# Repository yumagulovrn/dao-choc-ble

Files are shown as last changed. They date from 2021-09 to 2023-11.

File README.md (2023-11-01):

# Dao Choc BLE Keyboard

Dao Choc BLE (https://i.imgur.com/4VNZkyh.jpg)
Dao Choc BLE keyboard is an ergonomic wireless split keyboard for Kailh Choc switches based on MINEW MS88SF2 BLE module. This split keyboard is similar to Corne but it has an extra keys for brackets and international layouts as on Jorne or Jian.

Available in 44 and 42 key variants

Inspiration for the keyboard was taken from these keyboards:
- [le_chiff_ble](https://github.com/MangoIV/le_chiff_ble) by [MangoIV](https://github.com/MangoIV) - electrical circuit
- [Corne](https://github.com/foostan/crkbd) by [foostan](https://github.com/foostan) - thumb cluster
- [Jorne](https://github.com/joric/jorne) by [joric](https://github.com/joric) - extra pinky key
- [Jian](https://github.com/KGOH/Jian-Info) by [KGOH](https://github.com/KGOH) - extra pinky key and column staggering
- [Coren-ish Zen](https://lowprokb.ca/products/corne-ish-zen) by [DarrylDH](https://github.com/LOWPROKB) - choc-spacing, vibes

## Features

- Hotswapabble
- Long battery life
- ZMK firmware
- Low profile
- Choc Spacing (18mm x 17mm)

## Firmware

Latest compiled ZMK firmware for this keyboard can be found here: https://github.com/yumagulovrn/dao-zmk-config/releases/latest

Source Code: https://github.com/yumagulovrn/dao-zmk-config

## Bootloader

Latest compiled bootloader based on Adafruit nRF52 Bootloader can be found here: https://github.com/yumagulovrn/Adafruit_nRF52_Bootloader/releases/latest

Source code: https://github.com/yumagulovrn/Adafruit_nRF52_Bootloader/tree/dao

You will need separate device to flash the bootloader.

Guide "how to flash the bootloader" can be found [here](https://github.com/Ladniy/jiran-ble-lite/wiki/Firmware). You can literally follow these instructions step-by-step but with *.hex file from [here](https://github.com/yumagulovrn/Adafruit_nRF52_Bootloader/releases/latest)

## Gerbers

https://github.com/yumagulovrn/dao-choc-ble/releases/latest

## BOM

### PCB

| Reference | Name | Package  | Value | AliExpress | LCSC | Qty |
|---|---|---|---|---|---|-----|
| BT1 | JST | ? | 1.25mm 2pin 90° | [1.25mm 2pin 90° 50 pcs](https://aliexpress.com/item/10000064127272.html?sku_id=20000000117379413) | ? | 2 |
| C1-C2, C4-C5 | Capacitor | 0603 | 10uF | [10uF - 100 pcs](https://aliexpress.com/item/32966526545.html?sku_id=66569661174) | C19702  | 8 |
| C3 | Capacitor | 0603 | 1nF | [1nF - 100 pcs](https://aliexpress.com/item/32966526545.html?sku_id=66569661147) | C1588 | 2 |
| C6-C7 | Capacitor | 0603 | 4.7uF | [4.7uF 100 pcs](https://aliexpress.com/item/32966526545.html?sku_id=66569661173) | C19666  | 4 |
| D1-D22 | Diode | SOD-323  | 1N4148WS | [1N4148WS SOD-323 - 100 pcs](https://aliexpress.com/item/32849879904.html?sku_id=65195962305) | C57759  | 44  |
| D23 | Diode | SOD-123  | 1N5819W | [1N5819W SOD-123 - 100 pcs](https://aliexpress.com/item/32849879904.html?sku_id=65195962304) | C169540 | 2 |
| D24 | LED | 0603 | RED | [0603 RED - 100 pcs](https://aliexpress.com/item/1206456185.html?sku_id=65106628406) | C2286 | 2 |
| D25 | LED | 0603 | BLUE | [0603 BLUE - 100 pcs](https://aliexpress.com/item/1206456185.html?sku_id=65106628409) | C72041  | 2 |
| F1 | Fuse | 1206 | 500mA | [1206 500mA - 50 pcs](https://aliexpress.com/item/32907456681.html?sku_id=12000033093354867) | C355568 | 2 |
| J1 | USB Receptacle | ? | ? | [1.6mm - 10 pcs](https://aliexpress.com/item/32998900371.html?sku_id=12000021526913497) [0.8mm - 10 pcs](https://aliexpress.com/item/32998900371.html?sku_id=12000021526913496) | C168688 | 2 |
| K1-K22 | Kailh Choc Hotswap Socket | ? | ? | [90 pcs](https://aliexpress.com/item/33023283633.html?sku_id=10000000883911874) | ? | 44  |
| Q1 | P-Mosfet | SOT-23 | AO3401A | [50 pcs](https://aliexpress.com/item/32990534792.html) | C15127  | 2 |
| R1-R2 | Resistor | 0603 | 5.1k | [5.1K - 100 pcs](https://aliexpress.com/item/1005001436923851.html?sku_id=12000016109475028) | C23186  | 4 |
| R3 | Resistor | 0603 | 4.7 | [4.7R - 100 pcs](https://aliexpress.com/item/1005001436923851.html?sku_id=12000016109357956) | C23164  | 2 |
| R4 | Resistor | 0603 | 1M | [1M - 100 pcs](https://aliexpress.com/item/1005001436923851.html?sku_id=12000016109475082) | C22935  | 2 |
| R5 | Resistor | 0603 | **806k*** | [820K - 100pcs](https://aliexpress.com/item/1005001436923851.html?sku_id=12000016109475080) | C103828 | 2 |
| R6-R7 | Resistor | 0603 | 1k | [1K - 100pcs](https://aliexpress.com/item/1005001436923851.html?sku_id=12000016109475011) | C21190  | 4 |
| R8 | Resistor | 0603 | 2M | [2M - 100pcs](https://aliexpress.com/item/1005001436923851.html?sku_id=12000016109475089) | C22976  | 2 |
| R9 | Resistor | 0603 | **RPROG**** | [3.3K - 100pcs](https://aliexpress.com/item/1005001436923851.html?sku_id=12000016109475023) | C22978  | 2 |
| R10 | Resistor | 0603 | 100k | [100K - 100pcs](https://aliexpress.com/item/1005001436923851.html?sku_id=12000016109475058) | C25803  | 2 |
| SW1 | SPDT Switch | ? | MSK-12C02 | [50 pcs](https://aliexpress.com/item/4000685483225.html?sku_id=12000020983019153) | C431541 | 2 |
| SW2 | Tactile Button | ? | TS-1086E | [100 pcs](https://aliexpress.com/item/1005001846404680.html) | C455276 | 2 |
| U1 | MCU | ? | MINEW MS88SF2 | [1 pcs](https://aliexpress.com/item/4000101935456.html) | ? | 2 |
| U2 | ESD Protection IC | SOT-23-6 | USBLC6-2SC6 | [USBLC6-2SC6 - 10 pcs](https://aliexpress.com/item/32523780535.html?sku_id=12000027513378590) | C558442 | 2 |
| U3 | Voltage Regulator IC | SOT-23-5 | XC6220 | [30 pcs](https://aliexpress.com/item/4000271612572.html) | C86534  | 2 |
| U4 | Battery Charging IC | SOT-23-5 | MCP73831 | [10 pcs](https://aliexpress.com/item/32714249253.html) | C14879  | 2 |

**806k*** You can replace it with 820k resistor, but voltage sensing circuit (for battery status) will give somewhat invalid values

**RPROG**** Value depends on your battery capacity. For 300mAh battery should be 3.3K

### Other hardware

| Name | Qty  | AliExpress |
|---|---|---|
| LiPo Battery 502035 | 2 | [Global - 2 pcs](https://aliexpress.com/item/1005003717206039.html?sku_id=12000026915285813) [RU - 1 pcs](https://www.chipdip.ru/product/robiton-lp502035) |
| Standoff M2x5mm | 10 | [M2x5mm - 20 pcs](https://aliexpress.com/item/32597776358.html?sku_id=67114100494) |
| Standoff M2x8mm | 6 | [M2x8mm - 20 pcs](https://aliexpress.com/item/32597776358.html?sku_id=67114100497) |
| Screw M2x4mm | 32 | [Black M2x4mm - 50 pcs](https://aliexpress.com/item/32806166548.html?sku_id=66702152887) |
| Connector JST 1.25mm 2pin Male | 2 | [20 pcs](https://aliexpress.com/item/4000076660477.html) |
| Silicone Bumpers | 8-10 | [100 pcs](https://aliexpress.com/item/32912066603.html) |

## Cases

Dao has a pretty wide choice of cases.

### FR4 Case

Consists of:
* Bottom [42key](https://github.com/yumagulovrn/dao-choc-ble/releases/download/v1.0/pcb_42key-dao-choc-ble-bottom-gerber.zip) [44key](https://github.com/yumagulovrn/dao-choc-ble/releases/download/v1.0/pcb_44key-dao-choc-ble-bottom-gerber.zip)
* Plate [42key](https://github.com/yumagulovrn/dao-choc-ble/releases/download/v1.0/pcb_42key-dao-choc-ble-plate-gerber.zip) [44key](https://github.com/yumagulovrn/dao-choc-ble/releases/download/v1.0/pcb_44key-dao-choc-ble-plate-gerber.zip)
* [Shield](https://github.com/yumagulovrn/dao-choc-ble/releases/download/v1.0/pcb_dao-choc-ble-shield-gerber.zip)

**Note: plate should be 1.2mm thickness, bottom and shield can be any thickness you want (but I suggest 1.6mm)**

### 3D Printed Cases

#### OpenSCAD case from [shirokovroma](https://github.com/shirokovroma)

Has two variants:
* Bumper (you would need to have FR4 or printed plate, bottom and shield)
  * 42 keys [left](https://github.com/yumagulovrn/dao-choc-ble/releases/download/v1.0/3d_42key-bumper-left.stl) [right](https://github.com/yumagulovrn/dao-choc-ble/releases/download/v1.0/3d_42key-bumper-right.stl)
  * 44 keys [left](https://github.com/yumagulovrn/dao-choc-ble/releases/download/v1.0/3d_44key-bumper-left.stl) [right](https://github.com/yumagulovrn/dao-choc-ble/releases/download/v1.0/3d_44key-bumper-right.stl)
* Full (you would need to have FR4 or printed plate and shield)
  * 42 keys [left](https://github.com/yumagulovrn/dao-choc-ble/releases/download/v1.0/3d_42key-case-left.stl) [right](https://github.com/yumagulovrn/dao-choc-ble/releases/download/v1.0/3d_42key-case-right.stl)
  * 44 keys [left](https://github.com/yumagulovrn/dao-choc-ble/releases/download/v1.0/3d_44key-case-left.stl) [right](https://github.com/yumagulovrn/dao-choc-ble/releases/download/v1.0/3d_44key-case-right.stl)

#### [Dao keyboard slim case by Grigory Pavlichenko](https://www.thingiverse.com/thing:5988122)

### CNC cases

#### [Dao Shield by Mposiblee](https://github.com/Mposiblee/DaoShield)

## To Do List
- [x] Add BOM
- [x] Add images
- [x] Add descriptions
- [x] Add references to inspiration sources
- [x] Add link to a firmware
- [x] Add link to a bootloader
- [x] Make release v1.0

## Contacts

Telegram: https://ergonautkb.t.me

Telegram (ru): https://ergonautkb_ru.t.me

## Support and Warranty

lmao

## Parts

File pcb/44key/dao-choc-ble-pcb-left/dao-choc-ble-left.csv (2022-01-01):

Source: | C:\Keyboards\dao-choc-ble\pcb\44key\dao-choc-ble-pcb-left\dao-choc-ble-left.kicad_sch
Date: | 01.01.2022 14:03:32
Tool: | Eeschema (6.0.0)
Generator: | C:\Program Files\KiCad\6.0\bin\scripting\plugins/bom_csv_grouped_by_value.py
Component Count: | 85
Individual Components:
Item | Qty | Reference(s) | Value | LibPart | Footprint | Datasheet | LCSC | Note
 |  | BT1 | Battery_Cell | Device:Battery_Cell | dao-choc-ble:Battery | ~
 |  | C1 | 10uF | Device:C_Small | Capacitor_SMD:C_0603_1608Metric | ~ | C19702
 |  | C2 | 10uF | Device:C_Small | Capacitor_SMD:C_0603_1608Metric | ~ | C19702
 |  | C3 | 1nF | Device:C_Small | Capacitor_SMD:C_0603_1608Metric | ~ | C1588
 |  | C4 | 10uF | Device:C_Small | Capacitor_SMD:C_0603_1608Metric | ~ | C19702
 |  | C5 | 10uF | Device:C_Small | Capacitor_SMD:C_0603_1608Metric | ~ | C19702
 |  | C6 | 4.7uF | Device:C_Small | Capacitor_SMD:C_0603_1608Metric | ~ | C19666
 |  | C7 | 4.7uF | Device:C_Small | Capacitor_SMD:C_0603_1608Metric | ~ | C19666
 |  | D1 | 1N4148WS | Device:D_Small | dao-choc-ble:D_SOD-323 | ~ | C57759
 |  | D2 | 1N4148WS | Device:D_Small | dao-choc-ble:D_SOD-323 | ~ | C57759
 |  | D3 | 1N4148WS | Device:D_Small | dao-choc-ble:D_SOD-323 | ~ | C57759
 |  | D4 | 1N4148WS | Device:D_Small | dao-choc-ble:D_SOD-323 | ~ | C57759
 |  | D5 | 1N4148WS | Device:D_Small | dao-choc-ble:D_SOD-323 | ~ | C57759
 |  | D6 | 1N4148WS | Device:D_Small | dao-choc-ble:D_SOD-323 | ~ | C57759
 |  | D7 | 1N4148WS | Device:D_Small | dao-choc-ble:D_SOD-323 | ~ | C57759
 |  | D8 | 1N4148WS | Device:D_Small | dao-choc-ble:D_SOD-323 | ~ | C57759
 |  | D9 | 1N4148WS | Device:D_Small | dao-choc-ble:D_SOD-323 | ~ | C57759
 |  | D10 | 1N4148WS | Device:D_Small | dao-choc-ble:D_SOD-323 | ~ | C57759
 |  | D11 | 1N4148WS | Device:D_Small | dao-choc-ble:D_SOD-323 | ~ | C57759
 |  | D12 | 1N4148WS | Device:D_Small | dao-choc-ble:D_SOD-323 | ~ | C57759
 |  | D13 | 1N4148WS | Device:D_Small | dao-choc-ble:D_SOD-323 | ~ | C57759
 |  | D14 | 1N4148WS | Device:D_Small | dao-choc-ble:D_SOD-323 | ~ | C57759
 |  | D15 | 1N4148WS | Device:D_Small | dao-choc-ble:D_SOD-323 | ~ | C57759
 |  | D16 | 1N4148WS | Device:D_Small | dao-choc-ble:D_SOD-323 | ~ | C57759
 |  | D17 | 1N4148WS | Device:D_Small | dao-choc-ble:D_SOD-323 | ~ | C57759
 |  | D18 | 1N4148WS | Device:D_Small | dao-choc-ble:D_SOD-323 | ~ | C57759
 |  | D19 | 1N4148WS | Device:D_Small | dao-choc-ble:D_SOD-323 | ~ | C57759
 |  | D20 | 1N4148WS | Device:D_Small | dao-choc-ble:D_SOD-323 | ~ | C57759
 |  | D21 | 1N4148WS | Device:D_Small | dao-choc-ble:D_SOD-323 | ~ | C57759
 |  | D22 | 1N4148WS | Device:D_Small | dao-choc-ble:D_SOD-323 | ~ | C57759
 |  | D23 | 1N5819W | Device:D_Schottky_Small | Diode_SMD:D_SOD-123 | ~ | C169540
 |  | D24 | RED | Device:LED_Small | LED_SMD:LED_0603_1608Metric | ~ | C2286
 |  | D25 | BLUE | Device:LED_Small | LED_SMD:LED_0603_1608Metric | ~ | C72041
 |  | F1 | 500mA | Device:Polyfuse_Small | Fuse:Fuse_1206_3216Metric | ~ | C355568
 |  | H1 | MountingHole 4.2mm | Mechanical:MountingHole | dao-choc-ble:Hole_4.2mm | ~
 |  | H2 | MountingHole 4.2mm | Mechanical:MountingHole | dao-choc-ble:Hole_4.2mm | ~
 |  | H3 | MountingHole 4.2mm | Mechanical:MountingHole | dao-choc-ble:Hole_4.2mm | ~
 |  | H4 | MountingHole 4.2mm | Mechanical:MountingHole | dao-choc-ble:Hole_4.2mm | ~
 |  | H5 | MountingHole 4.2mm | Mechanical:MountingHole | dao-choc-ble:Hole_4.2mm | ~
 |  | H6 | MountingHole 2.2mm | Mechanical:MountingHole | dao-choc-ble:Hole_2.2mm | ~
 |  | H7 | MountingHole 2.2mm | Mechanical:MountingHole | dao-choc-ble:Hole_2.2mm | ~
 |  | H8 | MountingHole 2.2mm | Mechanical:MountingHole | dao-choc-ble:Hole_2.2mm | ~
 |  | H9 | Slot | Mechanical:MountingHole | dao-choc-ble:Slot | ~
 |  | J1 | USB | Connector:USB_C_Receptacle_USB2.0 | dao-choc-ble:USB-C_C168688 | https://www.usb.org/sites/default/files/documents/usb_type-c.zip | C168688
 |  | J2 | PROG | Connector_Generic:Conn_01x04 | dao-choc-ble:PROG | ~
 |  | K1 | KEY_SWITCH | dao-choc-ble:KEY_SWITCH | dao-choc-ble:Kailh_PG1350_hotswap
 |  | K2 | KEY_SWITCH | dao-choc-ble:KEY_SWITCH | dao-choc-ble:Kailh_PG1350_hotswap
 |  | K3 | KEY_SWITCH | dao-choc-ble:KEY_SWITCH | dao-choc-ble:Kailh_PG1350_hotswap
 |  | K4 | KEY_SWITCH | dao-choc-ble:KEY_SWITCH | dao-choc-ble:Kailh_PG1350_hotswap
 |  | K5 | KEY_SWITCH | dao-choc-ble:KEY_SWITCH | dao-choc-ble:Kailh_PG1350_hotswap
 |  | K6 | KEY_SWITCH | dao-choc-ble:KEY_SWITCH | dao-choc-ble:Kailh_PG1350_hotswap
 |  | K7 | KEY_SWITCH | dao-choc-ble:KEY_SWITCH | dao-choc-ble:Kailh_PG1350_hotswap
 |  | K8 | KEY_SWITCH | dao-choc-ble:KEY_SWITCH | dao-choc-ble:Kailh_PG1350_hotswap
 |  | K9 | KEY_SWITCH | dao-choc-ble:KEY_SWITCH | dao-choc-ble:Kailh_PG1350_hotswap
 |  | K10 | KEY_SWITCH | dao-choc-ble:KEY_SWITCH | dao-choc-ble:Kailh_PG1350_hotswap
 |  | K11 | KEY_SWITCH | dao-choc-ble:KEY_SWITCH | dao-choc-ble:Kailh_PG1350_hotswap
 |  | K12 | KEY_SWITCH | dao-choc-ble:KEY_SWITCH | dao-choc-ble:Kailh_PG1350_hotswap
 |  | K13 | KEY_SWITCH | dao-choc-ble:KEY_SWITCH | dao-choc-ble:Kailh_PG1350_hotswap
 |  | K14 | KEY_SWITCH | dao-choc-ble:KEY_SWITCH | dao-choc-ble:Kailh_PG1350_hotswap
 |  | K15 | KEY_SWITCH | dao-choc-ble:KEY_SWITCH | dao-choc-ble:Kailh_PG1350_hotswap
 |  | K16 | KEY_SWITCH | dao-choc-ble:KEY_SWITCH | dao-choc-ble:Kailh_PG1350_hotswap
 |  | K17 | KEY_SWITCH | dao-choc-ble:KEY_SWITCH | dao-choc-ble:Kailh_PG1350_hotswap
 |  | K18 | KEY_SWITCH | dao-choc-ble:KEY_SWITCH | dao-choc-ble:Kailh_PG1350_hotswap
 |  | K19 | KEY_SWITCH | dao-choc-ble:KEY_SWITCH | dao-choc-ble:Kailh_PG1350_hotswap
 |  | K20 | KEY_SWITCH | dao-choc-ble:KEY_SWITCH | dao-choc-ble:Kailh_PG1350_hotswap
 |  | K21 | KEY_SWITCH | dao-choc-ble:KEY_SWITCH | dao-choc-ble:Kailh_PG1350_hotswap
 |  | K22 | KEY_SWITCH | dao-choc-ble:KEY_SWITCH | dao-choc-ble:Kailh_PG1350_hotswap
 |  | LOGO1 | OSHW-logo | dao-choc-ble:OSHW-logo | dao-choc-ble:OSHW-logo
 |  | Q1 | AO3401A | Transistor_FET:AO3401A | Package_TO_SOT_SMD:SOT-23 | http://www.aosmd.com/pdfs/datasheet/AO3401A.pdf | C15127
 |  | R1 | 5.1k | Device:R_Small | Resistor_SMD:R_0603_1608Metric | ~ | C23186
 |  | R2 | 5.1k | Device:R_Small | Resistor_SMD:R_0603_1608Metric | ~ | C23186
 |  | R3 | 4.7 | Device:R_Small | Resistor_SMD:R_0603_1608Metric | ~ | C23164
 |  | R4 | 1M | Device:R_Small | Resistor_SMD:R_0603_1608Metric | ~ | C22935
 |  | R5 | 806k | Device:R_Small | Resistor_SMD:R_0603_1608Metric | ~ | C103828
 |  | R6 | 1k | Device:R_Small | Resistor_SMD:R_0603_1608Metric | ~ | C21190
 |  | R7 | 1k | Device:R_Small | Resistor_SMD:R_0603_1608Metric | ~ | C21190
 |  | R8 | 2M | Device:R_Small | Resistor_SMD:R_0603_1608Metric | ~ | C22976
 |  | R9 | RPROG | Device:R_Small | Resistor_SMD:R_0603_1608Metric | ~ | C22978 | 3.3K for 300mAh
 |  | R10 | 100k | Device:R_Small | Resistor_SMD:R_0603_1608Metric | ~ | C25803
 |  | SW1 | ON_OFF | Switch:SW_SPDT | dao-choc-ble:MSK-12C02 | ~ | C431541
 |  | SW2 | RESET | Switch:SW_Push | dao-choc-ble:TS-1086E | ~ | C455276
 |  | U1 | MS88SF2 | dao-choc-ble:MS88SF2 | dao-choc-ble:MINEW_MS88SF2
 |  | U2 | USBLC6-2SC6 | Power_Protection:USBLC6-2SC6 | Package_TO_SOT_SMD:SOT-23-6 | https://www.st.com/resource/en/datasheet/usblc6-2.pdf | C558442
 |  | U3 | XC6220 | Regulator_Linear:XC6220B331MR | Package_TO_SOT_SMD:SOT-23-5 | https://www.torexsemi.com/file/xc6220/XC6220.pdf | C86534
 |  | U4 | MCP73831 | Battery_Management:MCP73831-2-OT | Package_TO_SOT_SMD:SOT-23-5 | http://ww1.microchip.com/downloads/en/DeviceDoc/20001984g.pdf | C14879
Collated Components:
Item | Qty | Reference(s) | Value | LibPart | Footprint | Datasheet | LCSC | Note
1 | 1 | BT1 | Battery_Cell | Device:Battery_Cell | dao-choc-ble:Battery | ~
2 | 4 | C1, C2, C4, C5 | 10uF | Device:C_Small | Capacitor_SMD:C_0603_1608Metric | ~ | C19702
3 | 1 | C3 | 1nF | Device:C_Small | Capacitor_SMD:C_0603_1608Metric | ~ | C1588
4 | 2 | C6, C7 | 4.7uF | Device:C_Small | Capacitor_SMD:C_0603_1608Metric | ~ | C19666
5 | 22 | D1, D2, D3, D4, D5, D6, D7, D8, D9, D10, D11, D12, D13, D14, D15, D16, D17, D18, D19, D20, D21, D22 | 1N4148WS | Device:D_Small | dao-choc-ble:D_SOD-323 | ~ | C57759
6 | 1 | D23 | 1N5819W | Device:D_Schottky_Small | Diode_SMD:D_SOD-123 | ~ | C169540
7 | 1 | D24 | RED | Device:LED_Small | LED_SMD:LED_0603_1608Metric | ~ | C2286
8 | 1 | D25 | BLUE | Device:LED_Small | LED_SMD:LED_0603_1608Metric | ~ | C72041
9 | 1 | F1 | 500mA | Device:Polyfuse_Small | Fuse:Fuse_1206_3216Metric | ~ | C355568
10 | 5 | H1, H2, H3, H4, H5 | MountingHole 4.2mm | Mechanical:MountingHole | dao-choc-ble:Hole_4.2mm | ~
11 | 3 | H6, H7, H8 | MountingHole 2.2mm | Mechanical:MountingHole | dao-choc-ble:Hole_2.2mm | ~
12 | 1 | H9 | Slot | Mechanical:MountingHole | dao-choc-ble:Slot | ~
13 | 1 | J1 | USB | Connector:USB_C_Receptacle_USB2.0 | dao-choc-ble:USB-C_C168688 | https://www.usb.org/sites/default/files/documents/usb_type-c.zip | C168688
14 | 1 | J2 | PROG | Connector_Generic:Conn_01x04 | dao-choc-ble:PROG | ~
15 | 22 | K1, K2, K3, K4, K5, K6, K7, K8, K9, K10, K11, K12, K13, K14, K15, K16, K17, K18, K19, K20, K21, K22 | KEY_SWITCH | dao-choc-ble:KEY_SWITCH | dao-choc-ble:Kailh_PG1350_hotswap
16 | 1 | LOGO1 | OSHW-logo | dao-choc-ble:OSHW-logo | dao-choc-ble:OSHW-logo
17 | 1 | Q1 | AO3401A | Transistor_FET:AO3401A | Package_TO_SOT_SMD:SOT-23 | http://www.aosmd.com/pdfs/datasheet/AO3401A.pdf | C15127
18 | 2 | R1, R2 | 5.1k | Device:R_Small | Resistor_SMD:R_0603_1608Metric | ~ | C23186
19 | 1 | R3 | 4.7 | Device:R_Small | Resistor_SMD:R_0603_1608Metric | ~ | C23164
20 | 1 | R4 | 1M | Device:R_Small | Resistor_SMD:R_0603_1608Metric | ~ | C22935
21 | 1 | R5 | 806k | Device:R_Small | Resistor_SMD:R_0603_1608Metric | ~ | C103828
22 | 2 | R6, R7 | 1k | Device:R_Small | Resistor_SMD:R_0603_1608Metric | ~ | C21190
23 | 1 | R8 | 2M | Device:R_Small | Resistor_SMD:R_0603_1608Metric | ~ | C22976
24 | 1 | R9 | RPROG | Device:R_Small | Resistor_SMD:R_0603_1608Metric | ~ | C22978 | 3.3K for 300mAh
25 | 1 | R10 | 100k | Device:R_Small | Resistor_SMD:R_0603_1608Metric | ~ | C25803
26 | 1 | SW1 | ON_OFF | Switch:SW_SPDT | dao-choc-ble:MSK-12C02 | ~ | C431541
27 | 1 | SW2 | RESET | Switch:SW_Push | dao-choc-ble:TS-1086E | ~ | C455276
28 | 1 | U1 | MS88SF2 | dao-choc-ble:MS88SF2 | dao-choc-ble:MINEW_MS88SF2
29 | 1 | U2 | USBLC6-2SC6 | Power_Protection:USBLC6-2SC6 | Package_TO_SOT_SMD:SOT-23-6 | https://www.st.com/resource/en/datasheet/usblc6-2.pdf | C558442
30 | 1 | U3 | XC6220 | Regulator_Linear:XC6220B331MR | Package_TO_SOT_SMD:SOT-23-5 | https://www.torexsemi.com/file/xc6220/XC6220.pdf | C86534
31 | 1 | U4 | MCP73831 | Battery_Management:MCP73831-2-OT | Package_TO_SOT_SMD:SOT-23-5 | http://ww1.microchip.com/downloads/en/DeviceDoc/20001984g.pdf | C14879

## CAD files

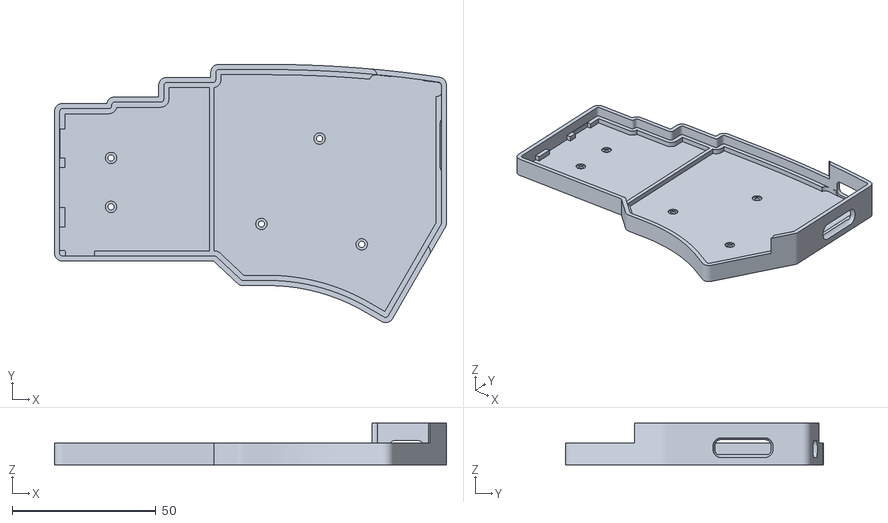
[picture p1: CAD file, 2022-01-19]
case/scad/42key/full_left.stl
136.4 x 89.9 x 14.6

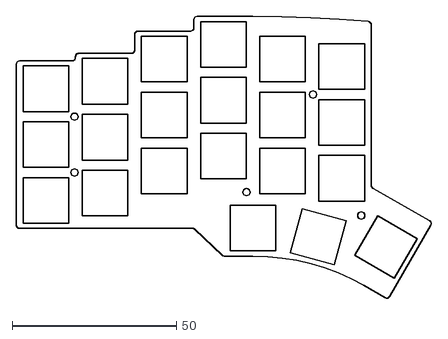
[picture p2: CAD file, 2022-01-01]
case/dxf/42key/dao-choc-ble-plate.dxf
126.4 x 85.9

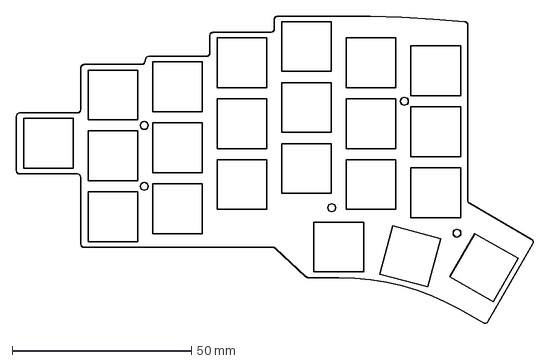
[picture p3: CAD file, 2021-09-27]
case/dxf/44key/dao-choc-ble-plate.dxf
144.4 x 85.9 mm

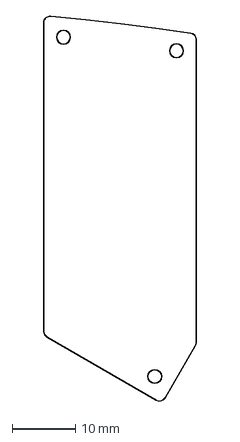
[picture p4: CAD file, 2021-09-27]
case/dxf/dao-choc-ble-shield.dxf
24.0 x 60.8 mm

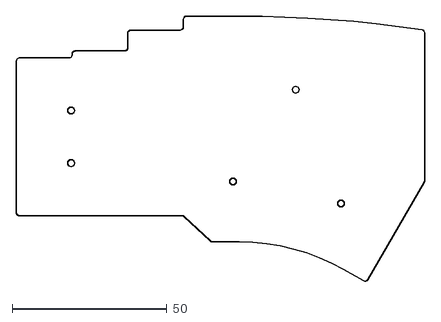
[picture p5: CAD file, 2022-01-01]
case/dxf/42key/dao-choc-ble-bottom.dxf
132.0 x 85.9

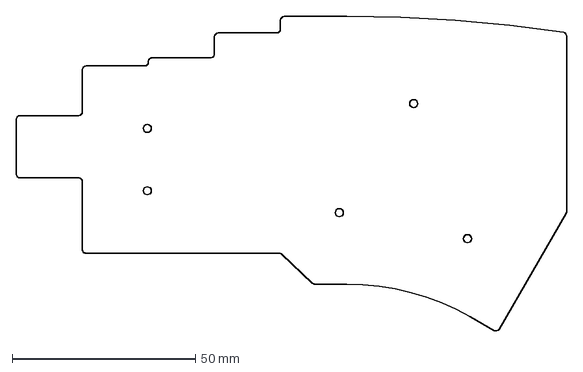
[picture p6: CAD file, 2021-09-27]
case/dxf/44key/dao-choc-ble-bottom.dxf
150.0 x 85.9 mm

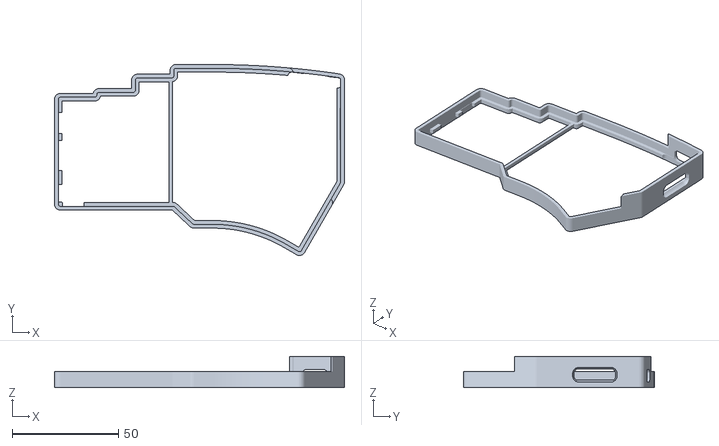
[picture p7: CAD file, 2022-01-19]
case/scad/42key/border_left.stl
136.4 x 89.9 x 14.6

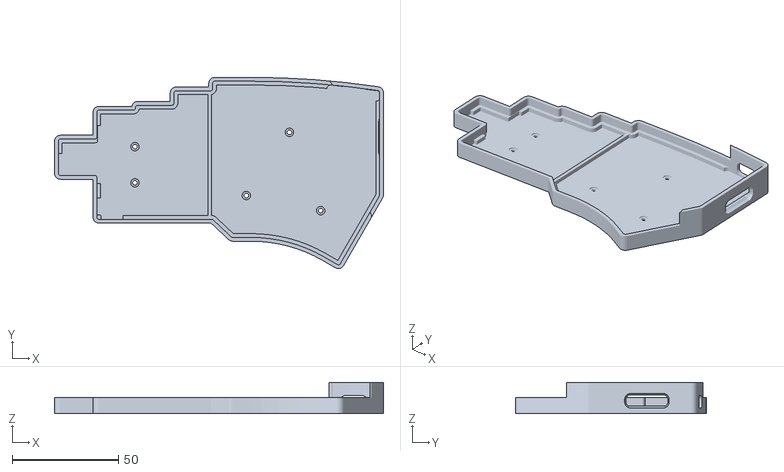
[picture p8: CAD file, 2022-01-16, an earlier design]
case/scad/44key/full_left.stl
154.6 x 89.9 x 14.6

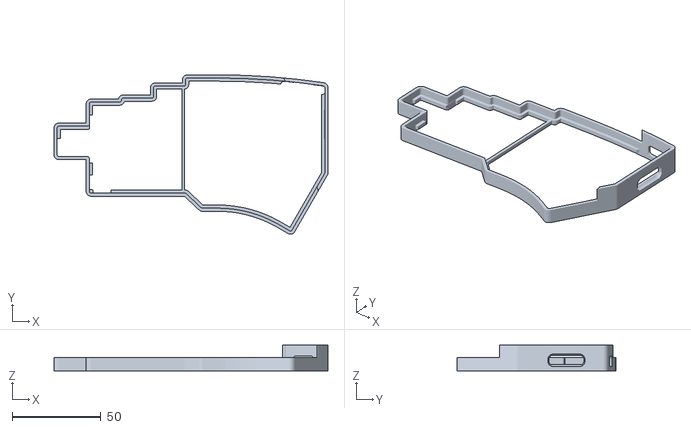
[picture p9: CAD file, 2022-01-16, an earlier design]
case/scad/44key/border_left.stl
154.6 x 89.9 x 14.6

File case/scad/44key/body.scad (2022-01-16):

$fn = 20;
include <bottom.scad>
left = false;
draw_bottom = true;
wall_height = 7.6;
bottom_thickness = 1.6;
wall_width = 1.8;
wall_padding = 0;

module
plank_left()
{
    translate([ 52, -80, 0 ]) square([ 1.6, 100 ]);
}

module
plank_right()
{
    translate([ 55, -80, 0 ]) square([ 1.6, 100 ]);
}

module
sample_middle()
{
    import(file = "dao-choc-ble-bottom.svg");
}
module
sample_top()
{
    import(file = "dao-choc-ble-additional-wall.svg");
}

module
border2d_inner()
{
    minkowski()
    {
        sample_middle();
        circle(wall_width + wall_padding);
    }
}

module
border2d_outer()
{
    difference()
    {
        translate([ -30, -80, 0 ]) square(size = [ 170, 120 ]);
        border2d_inner();
    }
}

module
border()
{
    difference()
    {
        linear_extrude(height = wall_height, convexity = 10) border2d_inner();
        linear_extrude(height = wall_height, convexity = 10) minkowski()
        {
            sample_middle();
            circle(wall_padding);
        }
        linear_extrude(height = wall_height, convexity = 10) sample_middle();
    }
}

module
middle()
{
    linear_extrude(height = 2, convexity = 10)

        difference()
    {
        union()
        {
            minkowski()
            {
                difference()
                {
                    minkowski()
                    {
                        sample_middle();
                        circle(wall_width / 2);
                    }
                    sample_middle();
                }
                circle(wall_width);
            }
            if (left) {
                plank_left();
            } else {
                plank_right();
            }
        }
        border2d_outer();
    }
}

module
body()
{
    border();
    difference()
    {
        translate([ 0, 0, 1.6 ]) middle();

        color("blue") translate([ 0, -17, 0 ]) cube([ 14, 10, 14 ]);

        color("gray")

            difference()
        {
            translate([ -2, -66, 0 ]) cube([ 14, 25, 14 ]);
            translate([ -0.2, -51.2, 0 ]) cube([ 2, 2, 10 ]);
        }

        color("red") translate([ -19, -34.3, 0 ]) cube([ 24, 14, 14 ]);

        color("green") translate([ 109.6, 9, 0 ]) rotate([ 0, 0, -7 ])
            minkowski()
        {
            cube([ 21.6, 1, 4 ]);
            sphere(2);
        }

        translate([ 117, 12, 4 ]) rotate([ 0, 0, -7 ]) minkowski()
        {
            cube([ 8, 15, 8 ]);
            sphere(3);
        }
    }

    add_wall_height = 7;

    translate([ 0, 0, wall_height ])
        linear_extrude(height = add_wall_height, convexity = 10) difference()
    {
        border2d_inner();
        minkowski()
        {
            circle(wall_width + wall_padding + 0.2);
            sample_top();
        }
        sample_middle();
    }
}

module
body_with_holes() difference()
{
    body();
    translate([ 116.5, 6, 4.5 ]) minkowski()
    {
        cube([ 8, 8, 2 ]);
        sphere(2);
    }
    translate([ 134.5, -20, 5.5 ]) minkowski()
    {
        cube([ 9, 15, 1 ]);
        sphere(3);
    }
}

if (left) {
    body_with_holes();
} else {
    mirror([ 1, 0, 0 ]) body_with_holes();
}

if (draw_bottom) {
    if (left) {
        bottom();
    } else {
        mirror([ 1, 0, 0 ]) bottom();
    }
}

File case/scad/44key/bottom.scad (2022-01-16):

module
sample()
{
    import(file = "dao-choc-ble-bottom.svg");
}

bottom_thickness = 1.6;

module
bottom()
{
    holes = [
        [ 17.7, -17 ],
        [ 17.7, -34 ],
        [ 70.03, -39.97 ],
        [ 104.95, -47.06 ],
        [ 90.29, -10.26 ],
    ];

    difference()
    {
        linear_extrude(height = bottom_thickness, convexity = 10) sample();
        for (h = holes) {
            color("red") translate([ h[0], h[1], 1 ])
                cylinder(h = bottom_thickness * 10, r = 2);
        }

        for (h = holes) {
            color("red") translate([ h[0], h[1], -1 ])
                cylinder(h = bottom_thickness * 10, r = 1.1);
        }
    }
}

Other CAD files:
case/scad/42key/full_right.stl
case/scad/42key/border_right.stl
case/scad/44key/full_right.stl
case/scad/44key/border_right.stl
case/scad/source/body.scad
case/scad/source/bottom.scad

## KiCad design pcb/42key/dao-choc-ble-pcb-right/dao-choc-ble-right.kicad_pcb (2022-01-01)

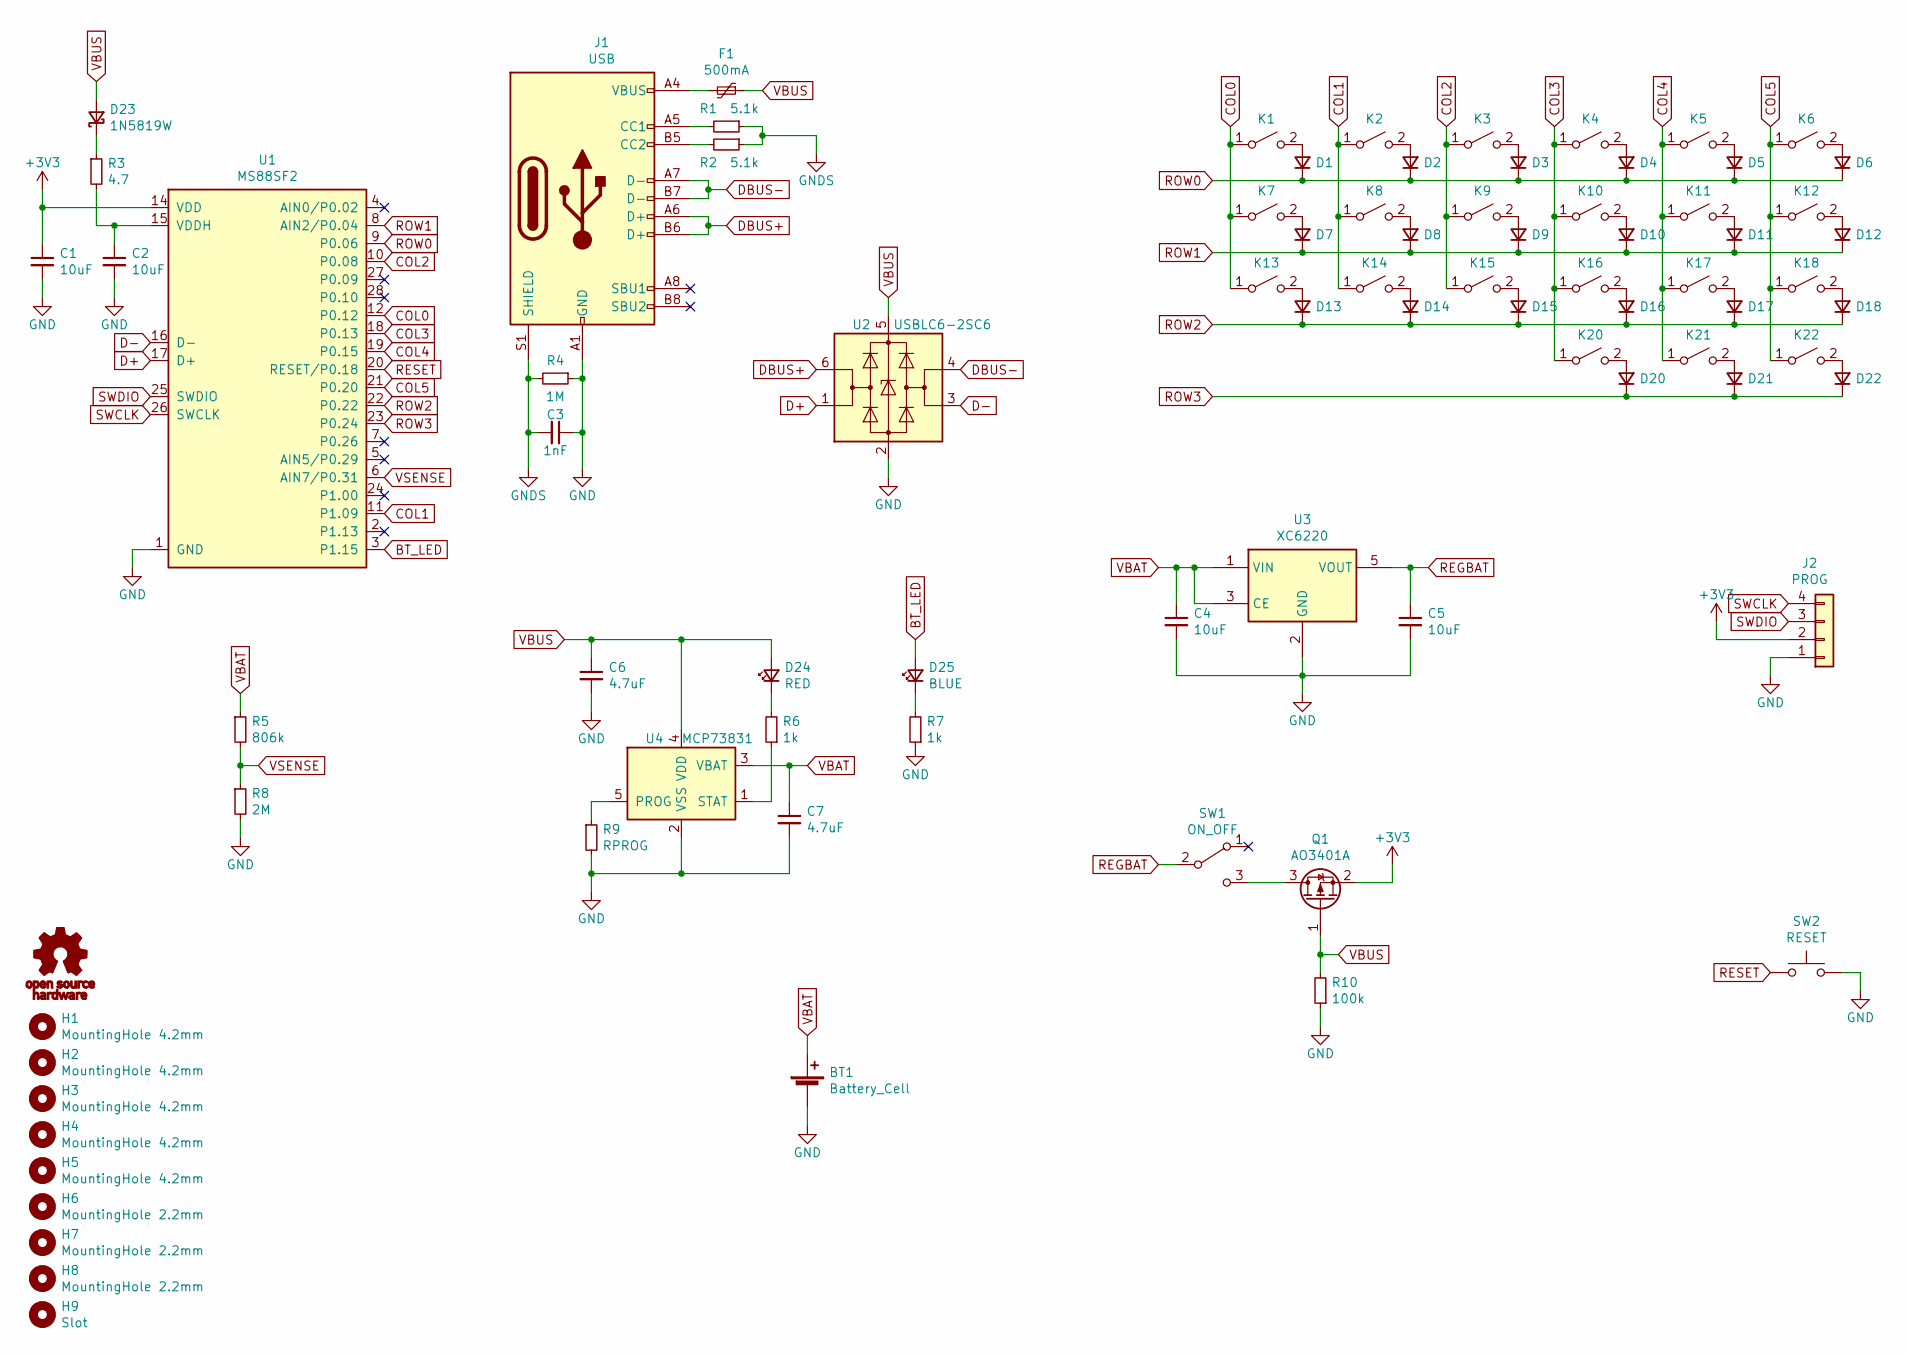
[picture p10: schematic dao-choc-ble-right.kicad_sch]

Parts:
BT1: Battery_Cell; Battery
C1, C2, C4, C5: 10uF; C_0603_1608Metric; LCSC C19702
C3: 1nF; C_0603_1608Metric; LCSC C1588
C6, C7: 4.7uF; C_0603_1608Metric; LCSC C19666
D1, D2, D3, D4, D5, D6, D7, D8, D9, D10, D11, D12, D13, D14, D15, D16, D17, D18, D20, D21, D22: 1N4148WS; D_SOD-323; LCSC C57759
D23: 1N5819W; D_SOD-123; LCSC C169540
D24: RED; LED_0603_1608Metric; LCSC C2286
D25: BLUE; LED_0603_1608Metric; LCSC C72041
F1: 500mA; Fuse_1206_3216Metric; LCSC C355568
H1, H2, H3, H4, H5: MountingHole 4.2mm; Hole_4.2mm
H6, H7, H8: MountingHole 2.2mm; Hole_2.2mm
H9: Slot
J1: USB; USB-C_C168688; LCSC C168688
J2: PROG
K1, K2, K3, K4, K5, K6, K7, K8, K9, K10, K11, K12, K13, K14, K15, K16, K17, K18, K20, K21, K22: KEY_SWITCH; Kailh_PG1350_hotswap
LOGO1: OSHW-logo
Q1: AO3401A; SOT-23; LCSC C15127
R1, R2: 5.1k; R_0603_1608Metric; LCSC C23186
R3: 4.7; R_0603_1608Metric; LCSC C23164
R4: 1M; R_0603_1608Metric; LCSC C22935
R5: 806k; R_0603_1608Metric; LCSC C103828
R6, R7: 1k; R_0603_1608Metric; LCSC C21190
R8: 2M; R_0603_1608Metric; LCSC C22976
R9: RPROG; R_0603_1608Metric; LCSC C22978
R10: 100k; R_0603_1608Metric; LCSC C25803
SW1: ON_OFF; MSK-12C02; LCSC C431541
SW2: RESET; TS-1086E; LCSC C455276
U1: MS88SF2; MINEW_MS88SF2
U2: USBLC6-2SC6; SOT-23-6; LCSC C558442
U3: XC6220; SOT-23-5; LCSC C86534
U4: MCP73831; SOT-23-5; LCSC C14879

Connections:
+3V3: C1.1, J2.2, Q1.2 (S), U1.14 (VDD)
BT_LED: D25.2 (A), U1.3 (P1.15)
COL0: K1.1 (A), K7.1 (A), K13.1 (A), U1.12 (P0.12)
COL1: K2.1 (A), K8.1 (A), K14.1 (A), U1.11 (P1.09)
COL2: K3.1 (A), K9.1 (A), K15.1 (A), U1.10 (P0.08)
COL3: K4.1 (A), K10.1 (A), K16.1 (A), K20.1 (A), U1.18 (P0.13)
COL4: K5.1 (A), K11.1 (A), K17.1 (A), K21.1 (A), U1.19 (P0.15)
COL5: K6.1 (A), K12.1 (A), K18.1 (A), K22.1 (A), U1.21 (P0.20)
D+: U1.17 (D+), U2.1 (I/O1)
D-: U1.16 (D-), U2.3 (I/O2)
DBUS+: J1.A6 (D+), J1.B6 (D+), U2.6 (I/O1)
DBUS-: J1.A7 (D-), J1.B7 (D-), U2.4 (I/O2)
GND: BT1.2 (-), C1.2, C2.2, C3.1, C4.2, C5.2, C6.2, C7.2, J1.A1 (GND), J1.A12 (GND), J1.B1 (GND), J1.B12 (GND), J2.1, R4.1, R7.1, R8.2, R9.2, R10.1, SW2.2, U1.1 (GND), U1.13 (GND), U2.2 (GND), U3.2 (GND), U4.2 (VSS)
GNDS: C3.2, J1.S1 (SHIELD), R1.1, R2.1, R4.2
unnamed: C2.1, R3.2, U1.15 (VDDH)
unnamed: D1.2 (A), K1.2 (B)
unnamed: D2.2 (A), K2.2 (B)
unnamed: D3.2 (A), K3.2 (B)
unnamed: D4.2 (A), K4.2 (B)
unnamed: D5.2 (A), K5.2 (B)
unnamed: D6.2 (A), K6.2 (B)
unnamed: D7.2 (A), K7.2 (B)
unnamed: D8.2 (A), K8.2 (B)
unnamed: D9.2 (A), K9.2 (B)
unnamed: D10.2 (A), K10.2 (B)
unnamed: D11.2 (A), K11.2 (B)
unnamed: D12.2 (A), K12.2 (B)
unnamed: D13.2 (A), K13.2 (B)
unnamed: D14.2 (A), K14.2 (B)
unnamed: D15.2 (A), K15.2 (B)
unnamed: D16.2 (A), K16.2 (B)
unnamed: D17.2 (A), K17.2 (B)
unnamed: D18.2 (A), K18.2 (B)
unnamed: D20.2 (A), K20.2 (B)
unnamed: D21.2 (A), K21.2 (B)
unnamed: D22.2 (A), K22.2 (B)
unnamed: D23.1 (K), R3.1
unnamed: D24.1 (K), R6.2
unnamed: D25.1 (K), R7.2
unnamed: F1.2, J1.A4 (VBUS), J1.A9 (VBUS), J1.B4 (VBUS), J1.B9 (VBUS)
unnamed: J1.A5 (CC1), R1.2
unnamed: J1.B5 (CC2), R2.2
unnamed: Q1.3 (D), SW1.3 (C)
unnamed: R6.1, U4.1 (STAT)
unnamed: R9.1, U4.5 (PROG)
REGBAT: C5.1, SW1.2 (B), U3.5 (VOUT)
RESET: SW2.1, U1.20 (RESET/P0.18)
ROW0: D1.1 (K), D2.1 (K), D3.1 (K), D4.1 (K), D5.1 (K), D6.1 (K), U1.9 (P0.06)
ROW1: D7.1 (K), D8.1 (K), D9.1 (K), D10.1 (K), D11.1 (K), D12.1 (K), U1.8 (AIN2/P0.04)
ROW2: D13.1 (K), D14.1 (K), D15.1 (K), D16.1 (K), D17.1 (K), D18.1 (K), U1.22 (P0.22)
ROW3: D20.1 (K), D21.1 (K), D22.1 (K), U1.23 (P0.24)
SWCLK: J2.4, U1.26 (SWCLK)
SWDIO: J2.3, U1.25 (SWDIO)
VBAT: BT1.1 (+), C4.1, C7.1, R5.1, U3.1 (VIN), U3.3 (CE), U4.3 (VBAT)
VBUS: C6.1, D23.2 (A), D24.2 (A), F1.1, Q1.1 (G), R10.2, U2.5 (VBUS), U4.4 (VDD)
VSENSE: R5.2, R8.1, U1.6 (AIN7/P0.31)

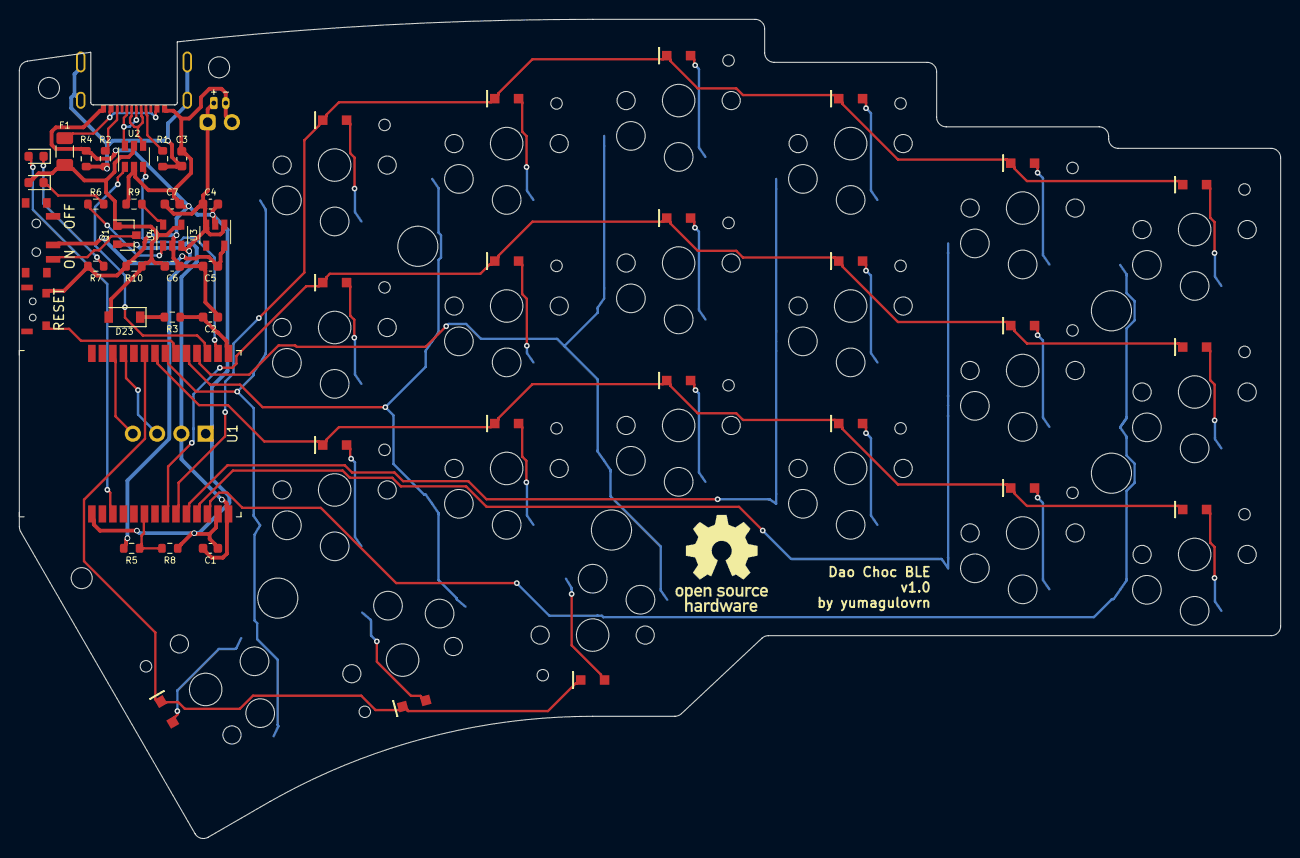
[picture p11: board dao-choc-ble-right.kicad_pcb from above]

Board: 2 copper layers, 132.0 x 85.7 mm, 82 parts (1 on the bottom side), 56 nets.

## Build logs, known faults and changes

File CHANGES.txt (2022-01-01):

2021.09.27 - Initial release of version 1.0 by Rafael Yumagulov
2022.01.01 - Added 42 key variant and BOM

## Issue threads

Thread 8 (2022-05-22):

help with bootloader and firmware installation

neokree, 2022-05-22:
Hello!

A month ago I found out this project and I started to look for split keyboards.
I really liked this one, but since I didn't find any store for it I decided to build it myself (maybe I should have looked at the russian telegram channel instead of the international one).
Anyway, now that I have received everything (except battery) and I soldered them together I would like to install the bootloader and firmware but I don't know how to do it.

When I connect the keyboard to the pc it doesn't do anything (it should flash one of the two leds?)
I saw in https://github.com/yumagulovrn/Adafruit_nRF52_Bootloader repo that it should enter DFU if I click the reset button two times, and maybe from that mode I should be able to see an USB drive that I could use to install the firmware? I tried multiple times but my macbook can't recognize it

Can you help me understand what's wrong?
I don't know if I should check for electric soldering or I just don't get how to install the bootloader

neokree, 2022-05-22:
Oh also when I bought the nRF52840 from MINEW on Aliexpress they asked me which configuration I wanted.
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
I choose the first configuration from this list, since it was the only one that supported USB & power supply.

yumagulovrn, 2022-05-22:
Hi!

Looks like I've completely forgot to mention bootloader in the repo, sorry :(

Long story short: you'll need a separate programmer ( J-Link or ST-Link or the Bluepill board or Raspberry Pi) to flash a bootloader, because MINEW chips are shipped without Adafruit bootloader preinstalled.

Relevant instructions can be found here https://github.com/joric/nrfmicro/wiki/Bootloader
But there are small differences:
* You should connect your PC only to programmer, and you'll need to connect all four contacts (power, ground. swd, swc) from programmer to Dao instead of only two in the instructions.
* You shound use bootloader file from https://github.com/yumagulovrn/Adafruit_nRF52_Bootloader/releases/tag/0.6.2-dao

If everything is done correctly, you will be able to flash Dao firmware via USB.

I'll add more detailed instructions next week

neokree, 2022-05-22:
Thank you for your fast response!

No problem for the instructions, I was more worried that I could have bricked the board 😓
It's my first time soldering, normally I work with software hehe

I will buy a programmer and try to install the bootloader

neokree, 2022-08-19:
Hello @yumagulovrn! After two order on Aliexpress today I finally received my J-Link programmer 💪

I followed the guide here: https://github.com/Ladniy/jiran-ble-lite/wiki/Firmware, which was super helpful, thank you

I flashed the .hex file using JFlashLite and showed "Completed"..
But now I'm stuck at installing the firmware, I have tried multiple times to double press the reset button after connecting the USB-C directly to my macbook but it doesn't mount a new device.
The blue led, which was blinking when connected with the J-Link programmer, it's completely off, even if I put the switch to ON.

Is there anything that It seems wrong to you? Any help is welcomed

Closed 2022-07-24.

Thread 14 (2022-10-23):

R9 value

fi0, 2022-10-23:
Is there a formula to calculate the R9 value based on the battery capacitance please? I'd like to use a 150mAh battery.

Closed 2023-03-29.

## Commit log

2021-10-17 feature: changed footprint for battery connector
    [dao-choc-ble-left.kicad_pcb, dao-choc-ble-right.kicad_pcb]
2022-01-01 feat: added 42key variant and BOM
    [dao-choc-ble-bottom.dxf, dao-choc-ble-bottom.kicad_pcb, dao-choc-ble-left.csv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]
2022-01-08 Add 806k resistor information
2022-01-16 scad body source files
    [body.scad, bottom.scad]
2022-01-16 scad case stl
    [border_left.stl, border_right.stl, full_left.stl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]
2022-01-19 Added 42 key variant for the 3d case + refactor
    [body.scad, border_left.stl, border_right.stl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]
2022-01-19 Fixed formatting
    [bottom.scad]
2022-07-24 fix: updated BOM
2022-07-24 feat: update links in BOM

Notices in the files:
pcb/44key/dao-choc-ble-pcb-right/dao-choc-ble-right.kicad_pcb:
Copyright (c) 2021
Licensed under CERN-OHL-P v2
